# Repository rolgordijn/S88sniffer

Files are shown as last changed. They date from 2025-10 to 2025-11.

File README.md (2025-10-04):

# 🏴‍☠️ S88 Sniffer – Arduino “Bus Hack”

With this Arduino sketch, you can **listen in on the S88 bus** and read the **occupancy detectors** of your model railway in real time.  
A bit of *piracy* — but the legal kind, with solder instead of swords. 😉

---

## 💡 What it does
The S88 sniffer taps into the **S88 bus** between your command station and the first S88 module.  
It shows the live state of all occupancy sensors and can **control relays or LEDS or whatever you want ** based on those signals — for example, to manage a **reverse loop**.

**First application:**  
Automatically switching a relay for a reverse loop, using two occupancy detectors (set/reset).

---

## ⚙️ Hardware
- Arduino Nano (or compatible microcontroller)  
- ULN2803 or transistor stage for driving relays or LEDs  
- S88 bus connection:
  - **CLOCK** → D2  
  - **LOAD**  → D3  
  - **DATA**  → D4  
  - **GND / +5V** as on standard S88  
- Optional relay or LED outputs

---

## 🧠 How it works
The S88 bus is basically one long **shift register**.  
On every **CLOCK** pulse, the next detector state appears on the **DATA** line.  
The **LOAD** line marks the start of a new scan.

The Arduino:
1. Listens to the `LOAD` and `CLOCK` signals  
2. Reads bits from `DATA`  
3. Builds a *frame* containing all detector states  
4. Applies **debounce filtering** to avoid noise  
5. Controls **relays** based on configurable logic (e.g., reverse loop control)

---

## 🧩 Code structure
The project is split into clean modules:

| File | Purpose |
|---|---|
| **Config.h** | Pin definitions and constants |
| **S88Bus.cpp/h** | Interrupt-based S88 frame reader |
| **MelderManager.cpp/h** | Debounce logic for occupancy sensors |
| **Relay.cpp/h** | Set/reset relay logic with debug output |
| **main.ino** | Main loop connecting everything together |

---

## ⚡ Example – relay rules
```cpp
Relay relay1("relay1", A0, 11, 13); // set = detector 11, reset = detector 13
Relay relay2("relay2", A1, 25, 34); // set = detector 25, reset = detector 34
```

When detector 11 is active → relay1 ON  
When detector 13 is active → relay1 OFF

---

## 📺 Debug output
On the serial monitor (115200 baud) you’ll see something like:

```
[1234 ms] detector 11 -> X
[1234 ms] relay1 -> ON (SET 11)
[1300 ms] detector 13 -> X
[1300 ms] relay1 -> OFF (RESET 13)
```

---

## 🧰 Software
- Arduino IDE or PlatformIO  
- Serial monitor at **115200 baud**

---

## 🤓 Credits
Project and code by Rian De Rous  
Inspired by the idea that *“sniffing the bus”* can be a perfectly respectable hobby. 😄  

#ModelRailway #S88 #Arduino #DIY #ReverseLoop #HackTheBus

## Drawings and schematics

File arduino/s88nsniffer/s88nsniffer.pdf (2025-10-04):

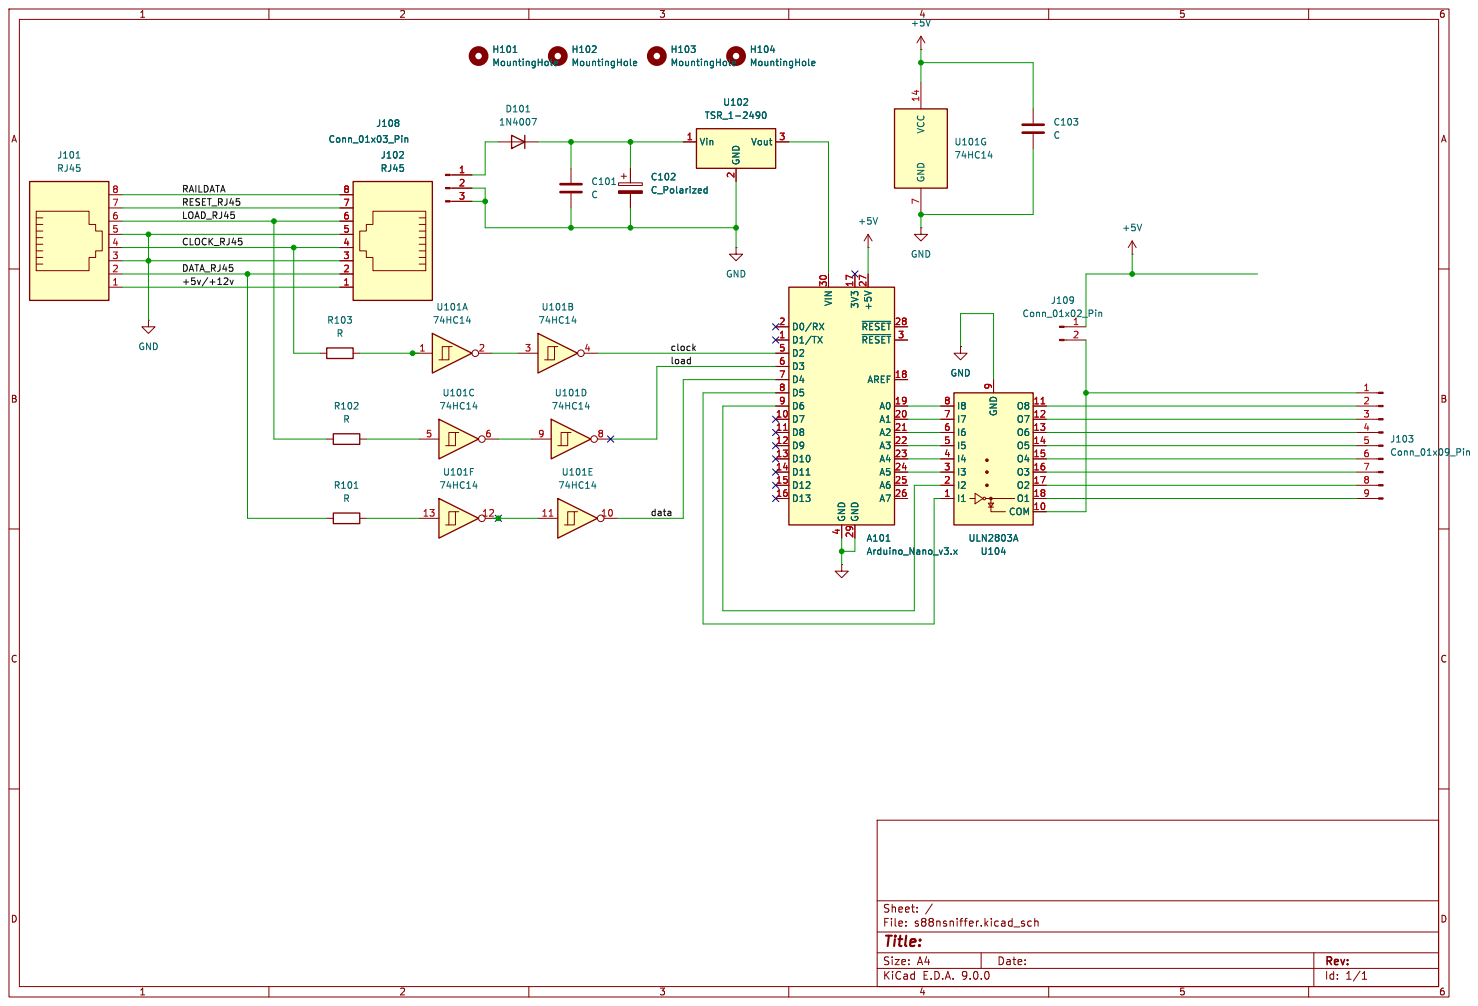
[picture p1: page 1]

2 Vout 3 H104 MountingHole C102 C_Polarized H101 MountingHole H102 MountingHole

Id: 1/1 Title: File: s88nsniffer.kicad_sch Sheet: /

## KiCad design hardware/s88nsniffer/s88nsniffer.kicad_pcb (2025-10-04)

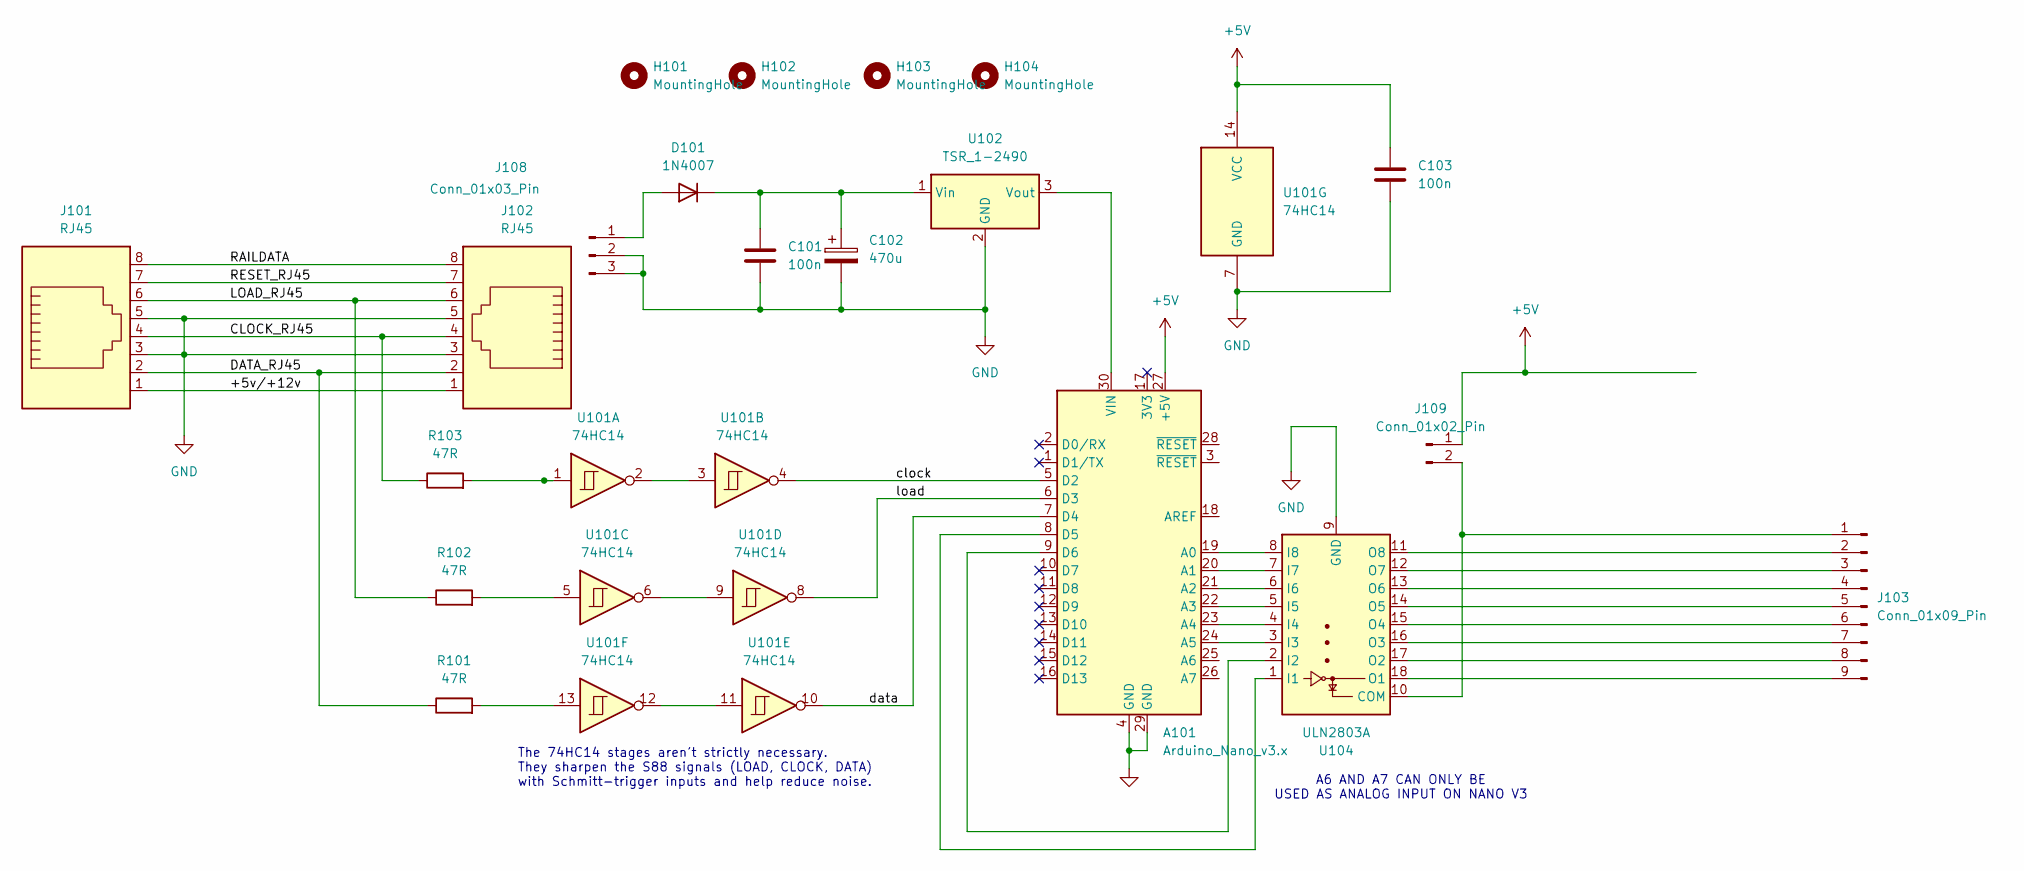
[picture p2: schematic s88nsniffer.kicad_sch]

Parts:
A101: Arduino_Nano_v3.x; Arduino_Nano
C101, C103: 100n; C_0805_2012Metric
C102: 470u; CP_Radial_D10.0mm_P3.50mm
D101: 1N4007; D_DO-41_SOD81_P10.16mm_Horizontal
H101, H102, H103, H104: MountingHole; MountingHole_4mm
J101, J102: RJ45; RJ45_Amphenol_RJHSE5380
J103: Conn_01x09_Pin; JST_PH_B9B-PH-K_1x09_P2.00mm_Vertical
J108: Conn_01x03_Pin; JST_PH_B3B-PH-K_1x03_P2.00mm_Vertical
J109: Conn_01x02_Pin; PinHeader_1x02_P2.54mm_Vertical
R101, R102, R103: 47R; C_0805_2012Metric
U101: 74HC14; DIP-14_W7.62mm
U102: TSR_1-2490; Converter_DCDC_TRACO_TSR-1_THT
U104: ULN2803A; DIP-18_W7.62mm

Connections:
+5V: A101.27 (+5V), C103.1, J109.1, U101.14 (VCC)
/+5v/+12v: J101.1, J102.1
/CLOCK_RJ45: J101.4, J102.4, R103.1
/DATA_RJ45: J101.2, J102.2, R101.1
/LOAD_RJ45: J101.6, J102.6, R102.1
/RAILDATA: J101.8, J102.8
/RESET_RJ45: J101.7, J102.7
/clock: A101.5 (D2), U101.4
/data: A101.7 (D4), U101.10
/load: A101.6 (D3), U101.8
GND: A101.4 (GND), A101.29 (GND), C101.2, C102.2, C103.2, J101.3, J101.5, J102.3, J102.5, J108.2, J108.3, U101.7 (GND), U102.2 (GND), U104.9 (GND)
unnamed: A101.19 (A0), U104.8 (I8)
unnamed: A101.20 (A1), U104.7 (I7)
unnamed: A101.21 (A2), U104.6 (I6)
unnamed: A101.22 (A3), U104.5 (I5)
unnamed: A101.23 (A4), U104.4 (I4)
unnamed: A101.24 (A5), U104.3 (I3)
unnamed: A101.8 (D5), U104.1 (I1)
unnamed: A101.9 (D6), U104.2 (I2)
unnamed: A101.30 (VIN), U102.3 (Vout)
unnamed: D101.2 (A), J108.1
unnamed: C101.1, C102.1, D101.1 (K), U102.1 (Vin)
unnamed: J103.1, J109.2, U104.10 (COM)
unnamed: J103.2, U104.11 (O8)
unnamed: J103.3, U104.12 (O7)
unnamed: J103.4, U104.13 (O6)
unnamed: J103.5, U104.14 (O5)
unnamed: J103.6, U104.15 (O4)
unnamed: J103.7, U104.16 (O3)
unnamed: J103.8, U104.17 (O2)
unnamed: J103.9, U104.18 (O1)
unnamed: R101.2, U101.13
unnamed: R102.2, U101.5
unnamed: R103.2, U101.1
unnamed: U101.2, U101.3
unnamed: U101.6, U101.9

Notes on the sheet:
The 74HC14 stages aren't strictly necessary. They sharpen the S88 signals (LOAD, CLOCK, DATA) with Schmitt-trigger inputs and help reduce noise.
A6 AND A7 CAN ONLY BE USED AS ANALOG INPUT ON NANO V3

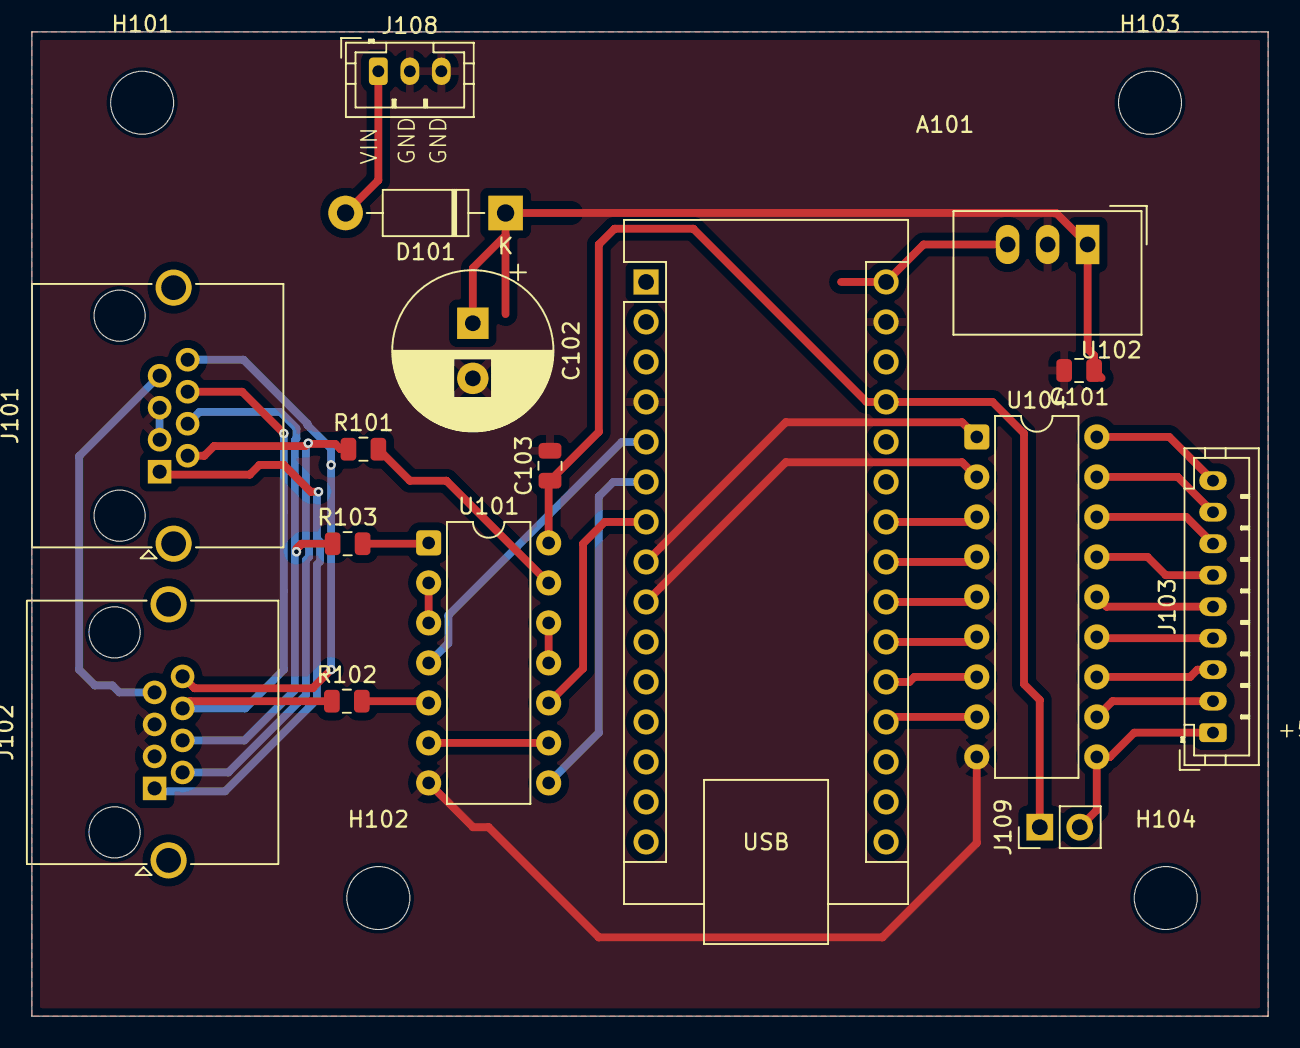
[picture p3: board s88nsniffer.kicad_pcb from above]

Board: 2 copper layers, 78.5 x 62.5 mm, 20 parts (0 on the bottom side), 36 nets.

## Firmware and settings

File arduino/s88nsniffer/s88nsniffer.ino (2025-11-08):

#include <Arduino.h>
#include "Config.h"
#include "S88Bus.h"
#include "MelderManager.h"
#include "Relay.h"

MelderManager melders;
Relay relay1("relay1", Config::RELAY1_PIN, Config::RELAY1_SET, Config::RELAY1_RESET);
Relay relay2("relay2", Config::RELAY2_PIN, Config::RELAY2_SET, Config::RELAY2_RESET);

void setup() {

  Serial.begin(115200);
  while (!Serial) {}

  Serial.println(F("S88 sniffer"));

  S88.begin();
  melders.begin();
  relay1.begin();
  relay2.begin();
}

void loop() {
  static uint32_t lastId = 0;
  Frame cur;
  

  
  if (S88.snapshot(cur)) {

    if (cur.id != lastId) {
      melders.updateFromFrame(cur);

      //digitalWrite(A0, melders.state(13));
      relay1.update(melders);
      relay2.update(melders);
      lastId = cur.id;
    }
  }

  
}

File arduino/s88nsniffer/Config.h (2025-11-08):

#pragma once
#include <Arduino.h>

namespace Config {
  constexpr uint8_t CLOCK_PIN = 2;
  constexpr uint8_t LOAD_PIN  = 3;
  constexpr uint8_t DATA_PIN  = 4;

  constexpr uint16_t N_MELDERS = 40;
  constexpr uint16_t DEBOUNCE_MS = 500;

  constexpr uint8_t RELAY1_PIN   = A0;
  constexpr uint16_t RELAY1_SET  = 13;
  constexpr uint16_t RELAY1_RESET= 11;

  constexpr uint8_t RELAY2_PIN   = A1;
  constexpr uint16_t RELAY2_SET  = 25;
  constexpr uint16_t RELAY2_RESET= 34;
}

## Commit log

2025-10-04 Initial combined project: Arduino + KiCad
    [s88nsniffer.kicad_pcb, s88nsniffer.kicad_sch]
2025-10-04 Move README from Arduino folder to project root
2025-10-04 add component values add some info on the schematic fixed a nr of pcb layout issues
    [s88nsniffer.kicad_pcb, s88nsniffer.kicad_sch]
2025-10-04 BOM details updated
    [s88nsniffer.kicad_sch]
2025-11-08 off by one error? 0,1,2,3 vs counting 1,2,3,4 in arrays...
    [Config.h, MelderManager.cpp, S88Bus.cpp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]
2025-11-11 interrupt guard
